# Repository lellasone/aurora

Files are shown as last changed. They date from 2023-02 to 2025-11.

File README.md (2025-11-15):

# Aurora
Aurora is an addressable LED controller with a graphical interface, audio input, and patterns programmed on an SD card.
It controls up to 8 WS2811-style LED strips in parallel.
A microphone and audio jack can be used for music visualization.
LED patterns are programmed in Lua and can be modified without rebooting by replacing the SD card.

[Interactive PCB BOM viewer](https://htmlpreview.github.io/?https://github.com/cruzsbrian/aurora/blob/main/aurora_hw/bom/ibom.html)

|  |  |
| --- | --- |

## Configuring LED Strips

`aurora_sw/src/lights.h` contains configuration for the number of strips and their lengths and directions.

`N_STRIPS` is the total number of strips (starting from the top connector).  
`LEDS_PER_STRIP` the maximum number of LEDs on a single strip.  
`N_LEDS` is the total number of LEDs (the sum of all the strip lengths, less than or equal to `N_STRIPS * LEDS_PER_STRIP`).  
`n_leds[N_STRIPS]` is an array of the strip lengths.  
`led_dirs[N_STRIPS]` is an array of the strip directions.
1 indicates the strip should start from its first LED, -1 indicates it should start from its last LED.

## Writing Patterns

When an SD card is inserted, Aurora interprets each Lua file in its root directory as a pattern.
The title of a pattern is its filename, minus the `.lua` extension.

Every pattern must define an `update()` function to display one frame of its animation, which will be called at 50 Hz.

Patterns can set LED colors with the `setRGB(i, r, g, b)` and `setHSV(i, h, s, v)` functions, where `i` is the index of the LED (starting at 1 to follow the Lua convention) and the other parameters specify the color (all values ranging from 0 to 1).
Patterns can also inspect the current color of an LED with `getRGB(i)`, which returns the red, green, and blue values from 0 to 1.

Calling `print(arg1, arg2, ...)` from Lua prints to the serial console.

A pattern can specify any number of "parameters" for itself, which appear as sliders in the UI, with `add_param(name, min, max, step, default)`, where `name` is a string, and `max`, `min`, `step`, `default` are floating point numbers.
The parameter will then be available as a global variable in the Lua environment for that pattern (so `name` must be a valid Lua variable name).

Here is an example pattern which displays a rainbow repeated a configurable number of times (set by `cycles`) moving at a configurable speed:
```Lua
add_param("speed", 0, 1, 0.05, 0.15)
add_param("cycles", 1, 10, 1, 1)

start = 0

function update()
    for i=1,N_LEDS do
        -- Calculate hue based on LED position, rainbow start position, and number of cycles.
        h = ((i - start) * cycles / N_LEDS) % 1
        
        -- Set LED to calculated hue, full saturation, 25% brightness.
        setHSV(i, h, 1, 0.25)
    end

    start = start + speed
end
```

# Compile / Upload:

## Uploading: 
Files can be uploaded to the device either by directly adding them to the sd card or using the upload.py utility. To use the upload.py utility navigate to the patterns directory and run the following command:
```
python upload.py [--save] [teensy port] [file name]
```
For example, to upload the Splashes pattern and save it to the sd card the command would be:
```
python upload.py --save /dev/ttyACM0 Splashes.lua
```

## Site Customization: : 
Although you can run the Aurora firmware as-is, you will probably want to go in and customize the LED settings to match the specific layout of your installation. This customization is done in the aurora_sw/src/lights.h file as follows. Examples are included for a few different possible configurations. 

Important Parameters:
- *LED_BRIGHTNESS:* How bright should "full" brightness be. Higher values will provide more light and color depth, but will also increase current use and may introduce color aberration on longer strips when many LEDs are lit. A default value of 100 will work in most environments. 
- *N_STRIPS:* How many different led strips there are. In this context a strip is defined as a group of LEDs which all share one signal line. 
- *LEDS_PER_STRIP:* The maximum number of LEDs on any one strip.
- *N_LEDS:* The total number of LEDs, this should be the sum of "n_leds".
- *n_leds:* How many LEDs there are in each strip. For custom installations it may be nessary to count, or to upload debug patterns to precisely determine this number. Incorrect values with result in lost pixels. 
- *led_dirs:* Which direction each strip runs relative to the direction of signal. You can pick either clockwise or counter-clockwise as the logic direction, but it must remain consistent to prevent animation jumps. Clockwise is a good default. 
## Windows Setup: 
The Windows install instructions assume that you have Version 2.x.x of the Arduino IDE installed, along with teensyduino which is used to upload code to the Teensy. Instructions for installing teensyduino (and links to arduino installers) can be found here: https://www.pjrc.com/teensy/teensyduino.html. It is definitely worth checking that your install works by uploading one of the teensy example scripts before proceeding. 

Setting up the build environment is pretty straightforward, but it does involve mucking around in the arduino libraries folder. If you have any questions definitely feel free to reach out. 

Using the arduino IDE Install: 
(Sketch -> Include Library -> Manage Libraries...)
 - SD, Version 1.3.0 or later. 
 - TFT_eSPI, Version 2.5.43 or later. 
 - lvgl, Version 8.4.0 exactly. 
 - arduinoFFT (for debugging, optional))
 
 Navigate to your a libraries folder (likely C:/Users/[Name]/Documents/Arduino/libraries) and clone the [arduinoLua](https://github.com/blackketter/LuaArduino) repo. 
 
 Now copy the lv_conf.h file from /aurora_sw/src/ to the top level of your Arduino libraries folder. This configures the GUI generator.
 
 In your arduino libraries folder, replace TFT_eSPI/User_Setup.h with the User_Setup.h file provided in aurora_sw/src/. This configures the pins and dimensions of the display itself. 
  
 You can now open src.ino with the Arduino IDE. 

 Select the board type "Teensy 4.0" (DMA is hardware-specific and won't compile for other devices). 
 
 Before uploading you will need to set the optimizer (tools -> optimize) to "Smallest Code".
 
 You are now ready to upload!

## Linux Setup: 
The Linux install instructions assume that you have Version 1.x.x of the Arduino IDE installed, along with teensyduino which is used to upload code to the Teensy. Instructions for installing teensyduino (and links to arduino installers) can be found here: https://www.pjrc.com/teensy/teensyduino.html. It is definitely worth checking that your install works by uploading one of the teensy example scripts before proceeding. 

Setting up the build environment is pretty straightforward, but it does involve mucking around in the arduino libraries folder. If you have any questions definitely feel free to reach out. 

Using the arduino IDE Install: 
(Sketch -> Include Library -> Manage Libraries...)
 - SD, Version 1.3.0 or later. 
 - TFT_eSPI, Version 2.5.43 or later. 
 - lvgl, Version 8.4.0 exactly. 
 - arduinoFFT (for debugging, optional)
 
 Navigate to your a libraries folder (likely /home/[name]/Arduino/libraries) and clone the [arduinoLua](https://github.com/blackketter/LuaArduino) repo. 
 
 Now copy the lv_conf.h file from /aurora_sw/src/ to the top level of your Arduino libraries folder. This configures the GUI generator.
 
 In your arduino libraries folder, replace TFT_eSPI/User_Setup.h with the User_Setup.h file provided in aurora_sw/src/. This configures the pins and dimensions of the display itself. 
 
 Rename /aurora_sw/src/main.cpp to /aurora_sw/src/main.ino so that it will be detected by the Arduino IDE. 
 
 You can now open src.ino with the Arduino IDE. 
 
 Before uploading you will need to set the optimizer (tools -> optimize) to "Smallest Code".
 
 You are now ready to upload!
 
 # Hardware Setup / Assembly: 
 
 ## Tips:
 - The MAX9814 is the board's most fiddly component, so if you are going to use the microphone, it pays to solder that first.
 - The fft_debug script can be used to check if the audio components are
   correctly installed. To use it install the script, and then play tones from
   your phone. The tones played and the tones reported on the serial monitor 
   should match to within 1hz or so over 200hz - 4000hz.

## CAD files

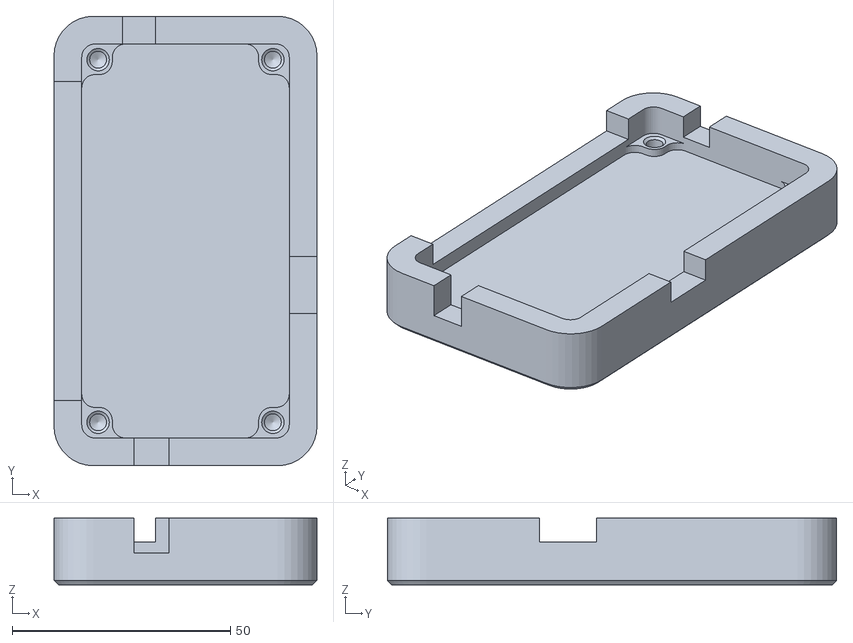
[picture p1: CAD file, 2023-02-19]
aurora_cad/french_case.STL
60.2 x 102.9 x 15.2

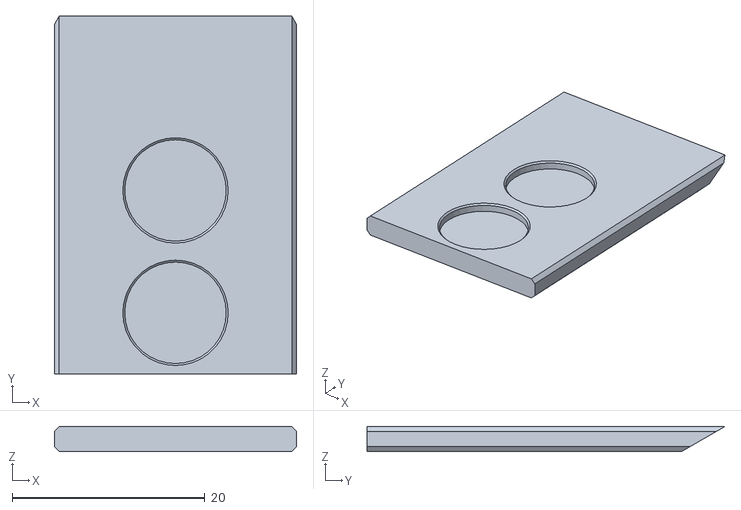
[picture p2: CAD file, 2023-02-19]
aurora_cad/cleat.STL
25.1 x 37.2 x 2.60

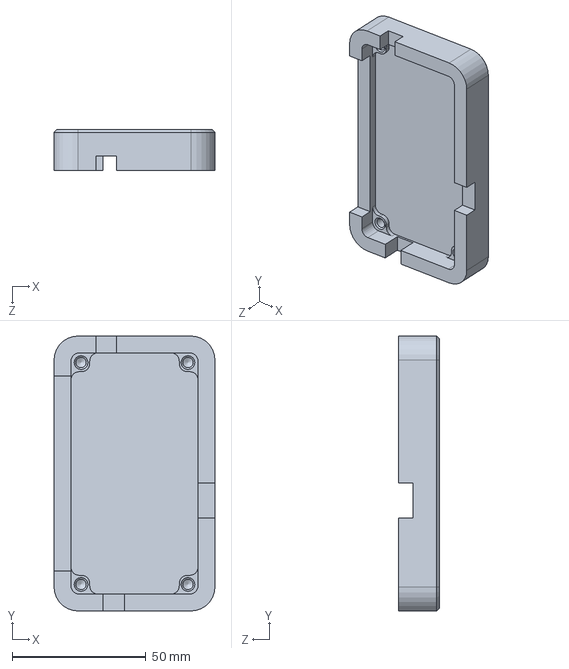
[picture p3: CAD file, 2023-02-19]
aurora_cad/basic_case.SLDPRT
60.2 x 102.9 x 15.2 mm

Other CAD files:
aurora_cad/basic_case.STL

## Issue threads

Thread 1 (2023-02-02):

Set up hardware

lellasone, 2023-02-02:
Physically build and integrate the device.

- [ ] Locate solder flux and a heatgun.
- [ ] Solder.
- [ ] Testing + Rework.
- [ ] Install.

lellasone, 2023-02-04:
Board is working, but audio is untested and I need to get connectors for interfacing with the main system.

lellasone, 2023-02-07:
Cables created, pull request made, sound checked (worked!). Now need to physically install, check if the same install can work on windows, and begin porting patterns.

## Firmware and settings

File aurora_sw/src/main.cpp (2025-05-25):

#include <vector>
#include <string>

#include <SD.h>
#include <Metro.h>

#include "ui.h"
#include "pattern.h"
#include "lights.h"


using std::vector;

#define SD_CS 17


bool card_inserted = false;

vector<Pattern> patterns;
unsigned int current_pattern_idx = 0;
long last_pattern_update = 0;

const long pattern_update_interval = 20; // ms

const long fps_update_millis = 1000;
long last_fps_update_time = 0;
long frames = 0;


vector<Pattern> get_patterns_from_sd(File dir) {
    vector<Pattern> patterns;

    // Loop through all files.
    while (File entry = dir.openNextFile()) {
        if (!entry.isDirectory()) {
            string filename = entry.name();
            Serial.println(filename.c_str());

            // If it has a lua extension, add it to the list.
            if (filename.substr(filename.length() - 4) == ".lua") {
                string name = filename.substr(0, filename.length() - 4);
                patterns.push_back(Pattern(patterns.size(), name, filename));
            }
        }
        entry.close();
    }

    return patterns;
}


void load_pattern(unsigned int idx) {
    if (idx >= patterns.size()) return;

    Serial.print(F("Loading pattern "));
    Serial.println(patterns[idx].name.c_str());

    // Unload current pattern.
    patterns[current_pattern_idx].unload();

    lights::blank();

    // Load new pattern.
    patterns[idx].load();
    current_pattern_idx = idx;
}



void setup() {
    Serial.begin(115200);
    Serial.println("Starting up");

    ui::init();
    lights::init();

    // Try to initialize the SD card.
    // If inserted, load the pattern list. If not, show the card removed page.
    Serial.print(F("Initializing SD card..."));
    if (SD.begin(SD_CS)) {
        Serial.println(F("OK!"));
        card_inserted = true;
        patterns = get_patterns_from_sd(SD.open("/"));
        ui::populate_root_page(patterns);

        load_pattern(current_pattern_idx);
    } else {
        Serial.println(F("failed!"));
        ui::card_removed();
    }
}


void loop() {
    // Detect SD card insertion/removal.
    // If inserted, load the pattern list. If not, show the card removed page.
    if (SD.mediaPresent() && !card_inserted) {
        card_inserted = true;
        patterns = get_patterns_from_sd(SD.open("/"));
        ui::populate_root_page(patterns);

        load_pattern(current_pattern_idx);
    } else if (!SD.mediaPresent() && card_inserted) {
        card_inserted = false;
        ui::card_removed();

        patterns[current_pattern_idx].unload();
        current_pattern_idx = 0;
        ui::selected_pattern = 0;

        lights::blank();
    }

    ui::update();

    if (ui::selected_pattern != current_pattern_idx) {
        load_pattern(ui::selected_pattern);
    }

    // If pattern_update_interval has passed, update the current pattern.
    // Also update the FPS counter every fps_update_millis.
    if (millis() - last_pattern_update >= pattern_update_interval && current_pattern_idx < patterns.size()) {
        last_pattern_update = millis();

        // long start = millis();
        patterns[current_pattern_idx].update();
        lights::show();
        // Serial.print("Pattern update took: "); Serial.print(millis() - start); Serial.println("ms");

        if (millis() - last_fps_update_time >= fps_update_millis) {
            Serial.print("FPS: "); Serial.println(1000.0 * (double) frames / (double) (millis() - last_fps_update_time));
            last_fps_update_time = millis();
            frames = 0;
        }

        frames++;
    }

    // Check to see if serial data is available. If so, write it to the SD card for the current pattern and reload the pattern.
    if (Serial.available()) {
        // Read first line to see what the command is.
        string command = Serial.readStringUntil('\n').c_str();

        // Read the rest of the data
        string data;
        while (Serial.available()) {
            data += (char) Serial.read();
        }

        Serial.println("Received on serial: ");
        Serial.println(command.c_str());
        Serial.println(data.c_str());

        if (command == "LOAD" || command == "SAVE") {
            lights::blank();
            patterns[current_pattern_idx].upload_code(data.c_str());
        }

        if (command == "SAVE") {
            patterns[current_pattern_idx].save_code(data.c_str());
        }
    }

    delay(1);
}

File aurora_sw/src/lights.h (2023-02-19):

#pragma once

#include <OctoWS2811.h>


// Hell-Lighting config
#define LED_BRIGHTNESS 100  // out of 255

#define N_STRIPS 2
#define LEDS_PER_STRIP 484
#define N_LEDS 967

const int n_leds[N_STRIPS] = {483, 484};
const int led_dirs[N_STRIPS] = {1, -1};

// Hell-Lighting config
//#define LED_BRIGHTNESS 50  // out of 255
//
//#define N_STRIPS 4
//#define LEDS_PER_STRIP 356
//#define N_LEDS 1220
//
//const int n_leds[N_STRIPS] = {285, 349, 254, 332};
//const int led_dirs[N_STRIPS] = {1, -1, -1, 1};


// Brian's room config
// #define LED_BRIGHTNESS 255  // out of 255

// #define N_STRIPS 2
// #define LEDS_PER_STRIP 360
// #define N_LEDS 660

// const int n_leds[N_STRIPS] = {300, 360};
// const int led_dirs[N_STRIPS] = {1, -1};


const byte pin_list[8] = {0, 1, 2, 3, 4, 5, 6, 7};


namespace lights {

void init();
void show();
void blank();
void setRGB(int idx, double r, double g, double b);
void setHSV(int idx, double h, double s, double v);
void getRGB(int idx, double *r, double *g, double *b);

void hsv2rgb(double h, double s, double v, double *r, double *g, double *b);

extern OctoWS2811 leds;

}

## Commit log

2023-02-19 added case files (in progress)
    [basic_case.SLDPRT, basic_case.STL, cleat.STL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]
2025-05-25 Removed std namespace, required for compile with modern arduino
